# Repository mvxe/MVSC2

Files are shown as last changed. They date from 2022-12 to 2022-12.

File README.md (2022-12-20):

# MVSC2 - MV Stepper Controller V2 

Stepper controller using a STM32F411CEU6 and 6x TMC2208-LA-T.  
Intended as a 3D printer controller, or a standalone 6 stepper driver.  
Also has 6 connectors for endstops or servos.  
Includes design with magnetic proximity sensors as endstops using CH912LSR.  

Design files ready for production at JLCPCB (except connectors, TODO).  

NOTE:  
- In the design I use a lower current setting for the stepper driver, which is meant for weaker steppers. Change sense resistor for normal stepper.  
- It is mean to be attached to a 2040 V slot profile, for cooling.  
- Since fabricating this, JLCPCB now supports connectors so this should be updated (hand soldering a USBC is not fun).  
- The power connector requires hand modification: the leads should be shortened such, and the support pins as well as not to portrude from the other side. Apply superglue for extra strength.  
- A compatible Marlin configuration to be added at a later date.

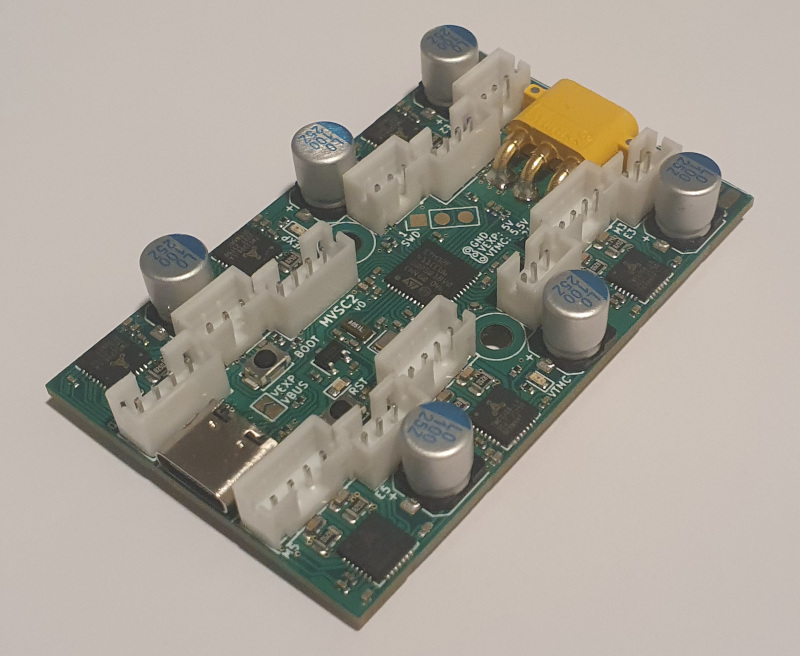
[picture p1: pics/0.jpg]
  
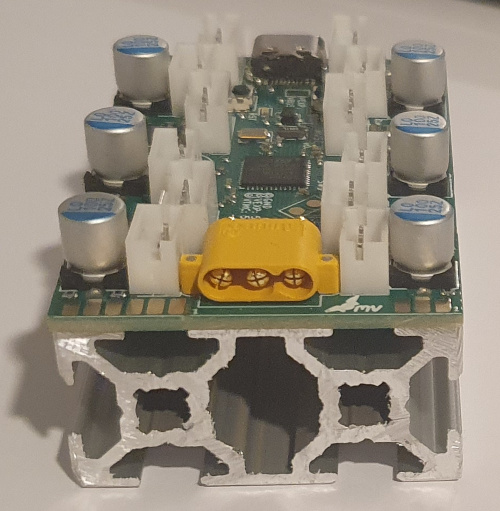
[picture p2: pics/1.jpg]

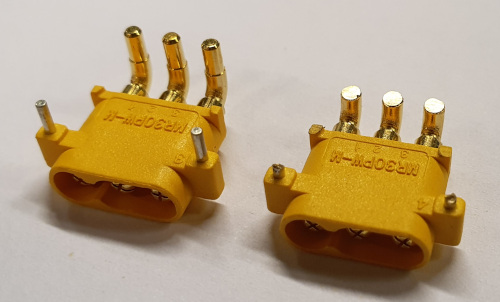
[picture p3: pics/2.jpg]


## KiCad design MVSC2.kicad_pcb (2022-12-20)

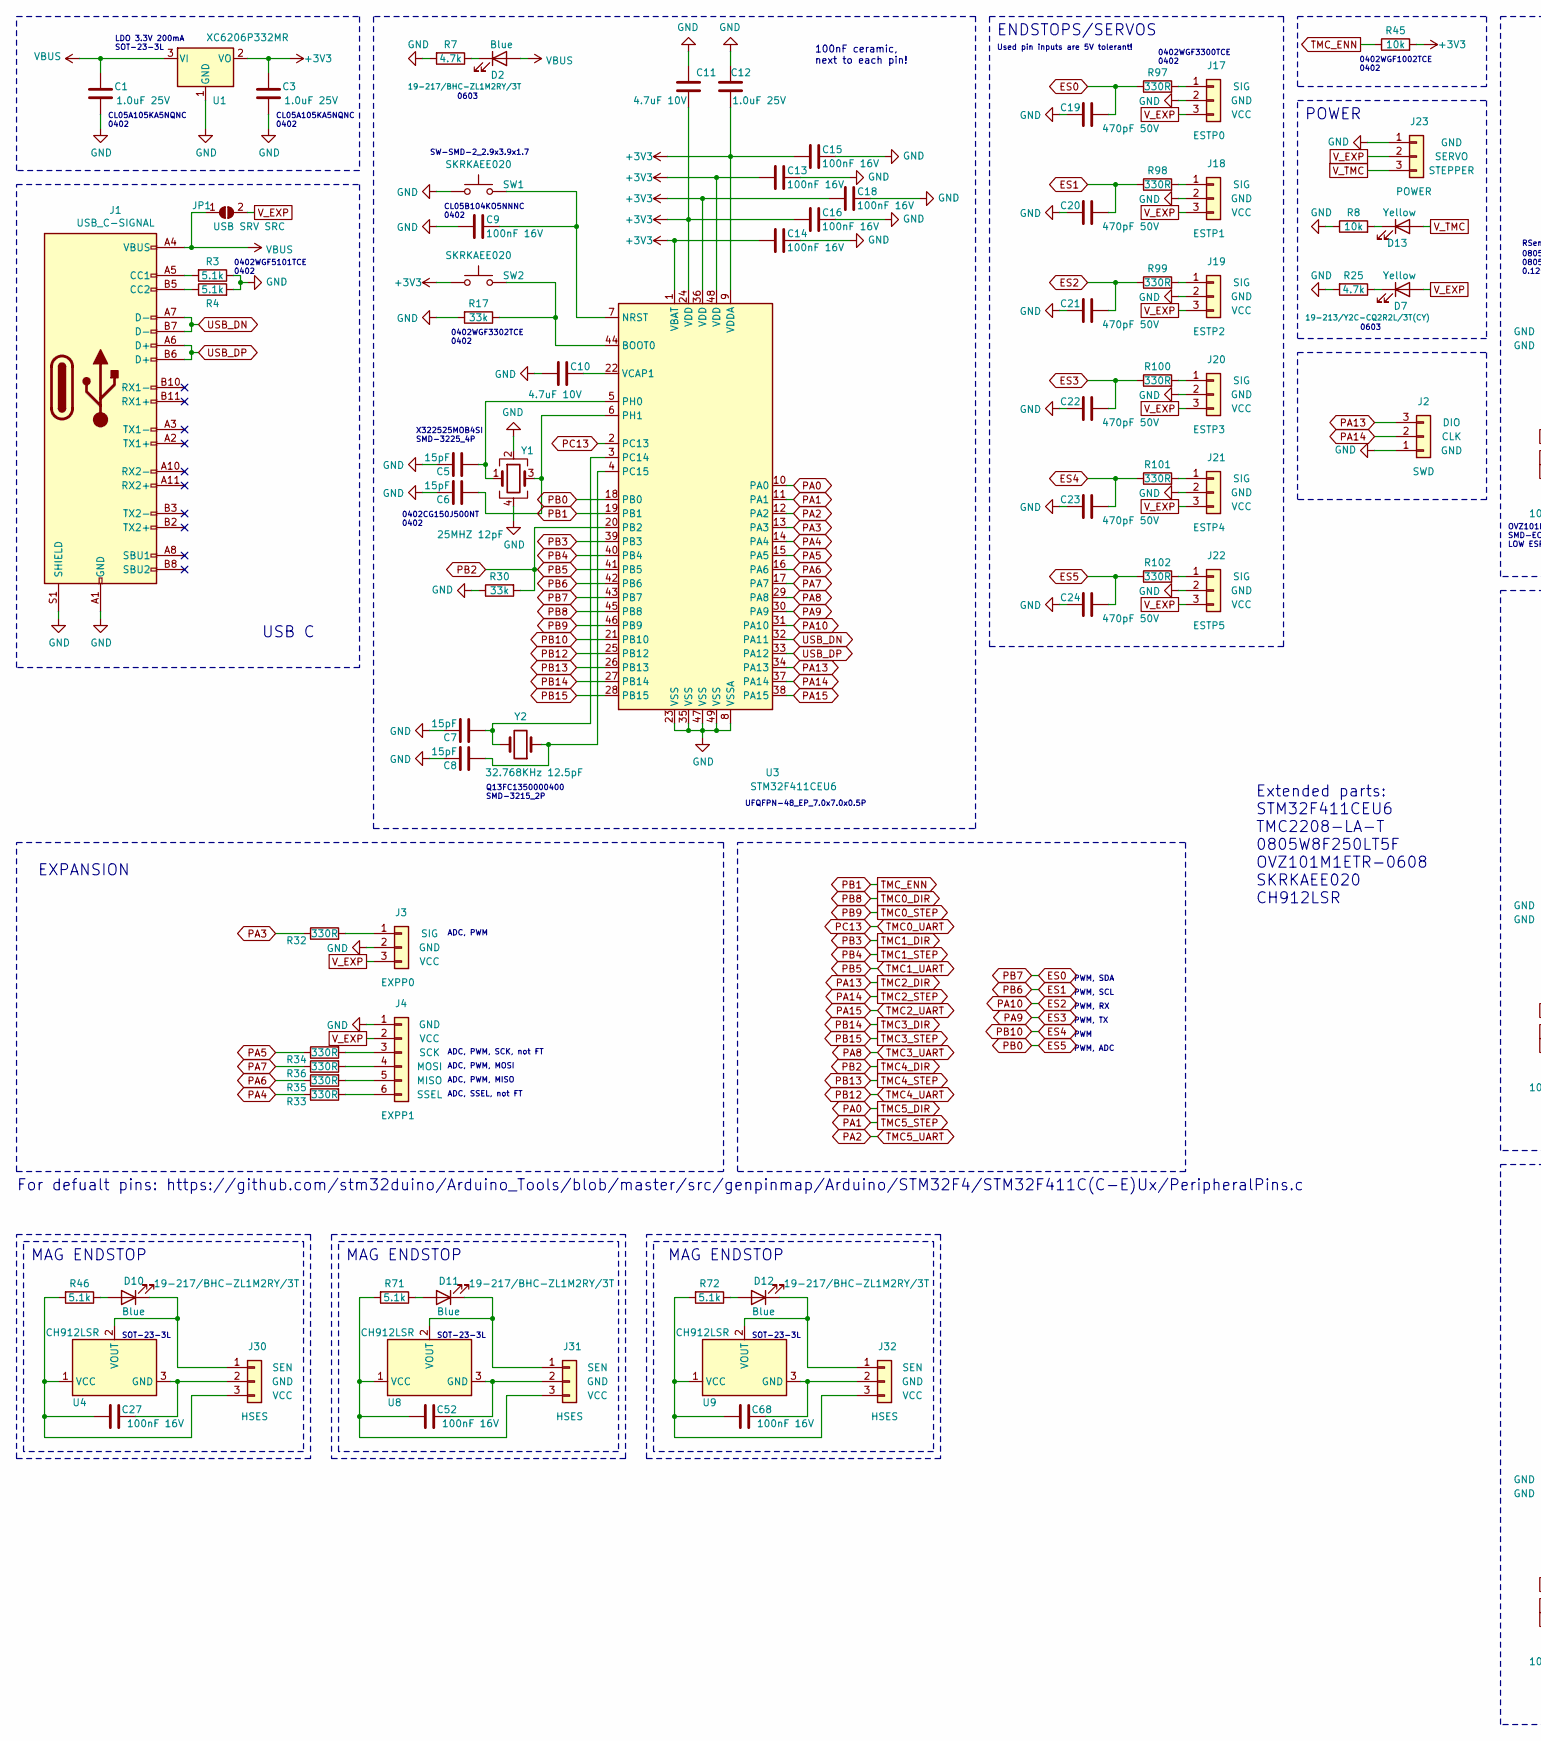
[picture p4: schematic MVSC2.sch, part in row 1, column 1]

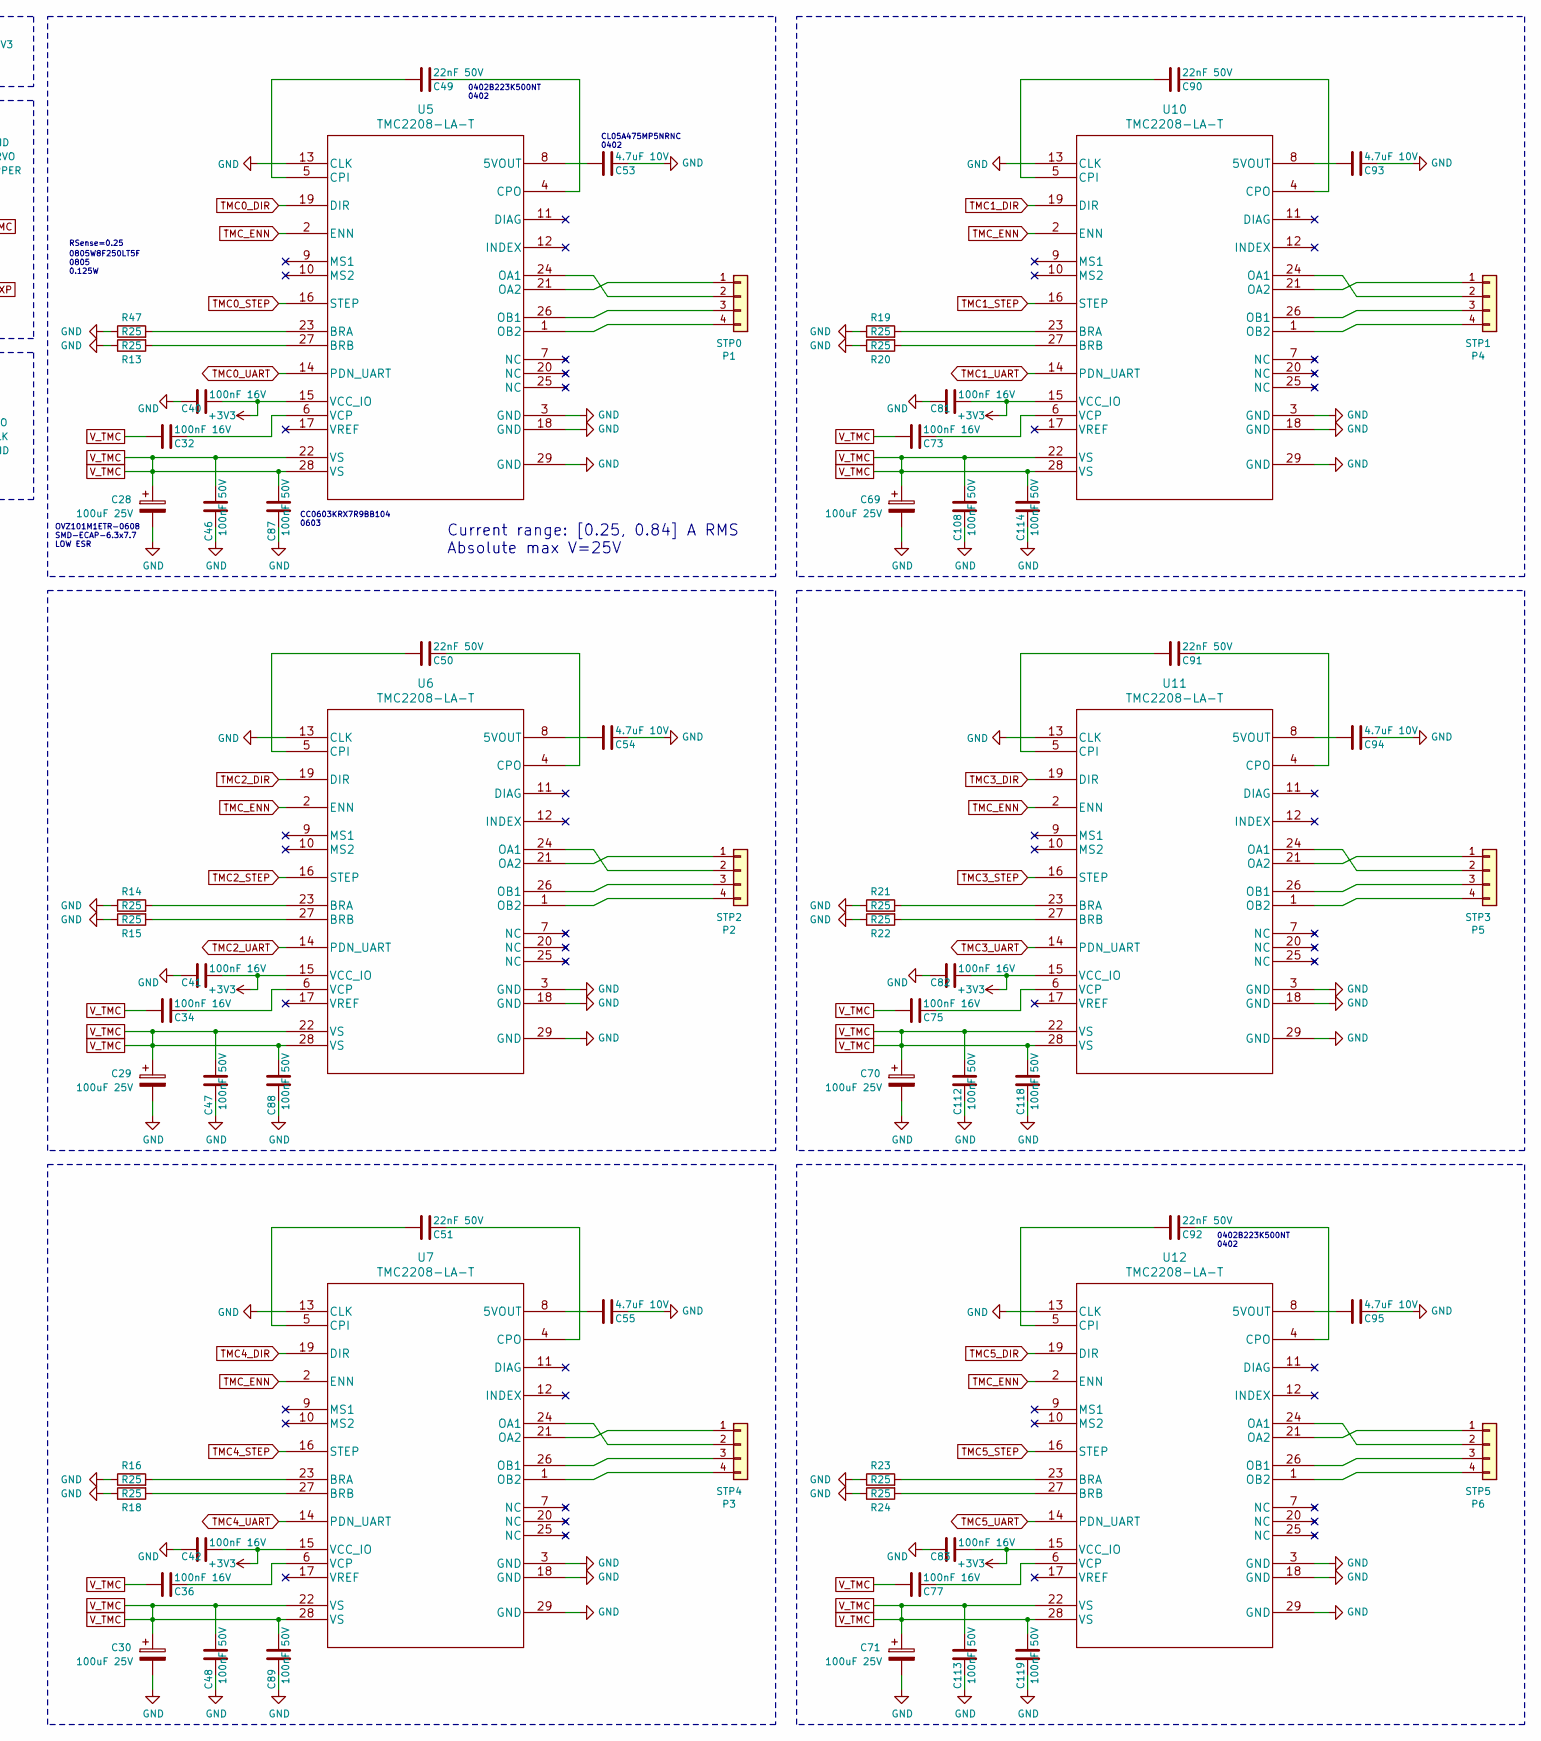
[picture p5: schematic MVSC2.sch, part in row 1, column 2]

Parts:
C1, C3, C12: 1.0uF 25V; C_0402_1005Metric; LCSC C52923
C5, C6, C7, C8: 15pF; C_0402_1005Metric; LCSC C1548
C9, C13, C14, C15, C16, C18, C27, C32, C34, C36, C40, C41, C42, C52, C68, C73, C75, C77, C81, C82, C83: 100nF 16V; C_0402_1005Metric; LCSC C1525
C10, C11, C53, C54, C55, C93, C94, C95: 4.7uF 10V; C_0402_1005Metric; LCSC C23733
C19, C20, C21, C22, C23, C24: 470pF 50V; C_0402_1005Metric; LCSC C1537
C28, C29, C30, C69, C70, C71: 100uF 25V; CP_Elec_6.3x7.7; LCSC C250084
C46, C47, C48, C87, C88, C89, C108, C112, C113, C114, C118, C119: 100nF 50V; C_0603_1608Metric; LCSC C14663
C49, C50, C51, C90, C91, C92: 22nF 50V; C_0402_1005Metric; LCSC C1532
D2, D10, D11, D12: Blue; LED_0603_1608Metric; LCSC C72041
D7, D13: Yellow; LED_0603_1608Metric; LCSC C72038
J1: USB_C-SIGNAL; USB_C_Receptacle_HRO_TYPE-C-31-M-12; LCSC C165948
J2: SWD; PinHeader_1x03_P2.54mm_Vertical
J3: EXPP0; JST_PH_B3B-PH-K_1x03_P2.00mm_Vertical
J4: EXPP1; JST_PH_B6B-PH-K_1x06_P2.00mm_Vertical
J17: ESTP0; JST_PH_B3B-PH-K_1x03_P2.00mm_Vertical
J18: ESTP1; JST_PH_B3B-PH-K_1x03_P2.00mm_Vertical
J19: ESTP2; JST_PH_B3B-PH-K_1x03_P2.00mm_Vertical
J20: ESTP3; JST_PH_B3B-PH-K_1x03_P2.00mm_Vertical
J21: ESTP4; JST_PH_B3B-PH-K_1x03_P2.00mm_Vertical
J22: ESTP5; JST_PH_B3B-PH-K_1x03_P2.00mm_Vertical
J23: POWER; AMASS_MR30PW-M_1x03_P3.50mm_Horizontal
J30, J31, J32: HSES; JST_PH_B3B-PH-K_1x03_P2.00mm_Vertical
JP1: USB SRV SRC; SolderJumper-2_P1.3mm_Open_TrianglePad1.0x1.5mm
P1: STP0; JST_PH_B4B-PH-K_1x04_P2.00mm_Vertical
P2: STP2; JST_PH_B4B-PH-K_1x04_P2.00mm_Vertical
P3: STP4; JST_PH_B4B-PH-K_1x04_P2.00mm_Vertical
P4: STP1; JST_PH_B4B-PH-K_1x04_P2.00mm_Vertical
P5: STP3; JST_PH_B4B-PH-K_1x04_P2.00mm_Vertical
P6: STP5; JST_PH_B4B-PH-K_1x04_P2.00mm_Vertical
R3, R4, R46, R71, R72: 5.1k; R_0402_1005Metric; LCSC C25905
R7, R25: 4.7k; R_0402_1005Metric; LCSC C25900
R8, R45: 10k; R_0402_1005Metric; LCSC C25744
R13, R14, R15, R16, R18, R19, R20, R21, R22, R23, R24, R47: R25; R_0805_2012Metric; LCSC C46216
R17, R30: 33k; R_0402_1005Metric; LCSC C25779
R32, R33, R34, R35, R36, R97, R98, R99, R100, R101, R102: 330R; R_0402_1005Metric; LCSC C25104
SW1, SW2: SKRKAEE020; SW_Push_SPST_NO_Alps_SKRK; LCSC C115357
U1: XC6206P332MR; SOT-23W; LCSC C5446
U3: STM32F411CEU6; QFN-48-1EP_7x7mm_P0.5mm_EP5.6x5.6mm; LCSC C60420
U4, U8, U9: CH912LSR; SOT-23W; LCSC C455294
U5, U6, U7, U10, U11, U12: TMC2208-LA-T; QFN-28-1EP_5x5mm_P0.5mm_EP3.35x3.35mm_ThermalVias; LCSC C115944
Y1: 25MHZ 12pF; Crystal_SMD_3225-4Pin_3.2x2.5mm; LCSC C9006
Y2: 32.768KHz 12.5pF; Crystal_SMD_3215-2Pin_3.2x1.5mm; LCSC C32346

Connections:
+3V3: C3.2, C11.2, C12.1, C13.2, C14.2, C15.2, C16.2, C18.2, C40.1, C41.1, C42.1, C81.1, C82.1, C83.1, R45.2, SW2.1, U1.2 (VO), U3.1 (VBAT), U3.9 (VDDA), U3.24 (VDD), U3.36 (VDD), U3.48 (VDD), U5.15 (VCC_IO), U6.15 (VCC_IO), U7.15 (VCC_IO), U10.15 (VCC_IO), U11.15 (VCC_IO), U12.15 (VCC_IO)
ES0: C19.1, R97.1, U3.43 (PB7)
ES1: C20.1, R98.1, U3.42 (PB6)
ES2: C21.1, R99.1, U3.31 (PA10)
ES3: C22.1, R100.1, U3.30 (PA9)
ES4: C23.1, R101.1, U3.21 (PB10)
ES5: C24.1, R102.1, U3.18 (PB0)
GND: C1.1, C3.1, C5.1, C6.1, C7.1, C8.1, C9.2, C10.2, C11.1, C12.2, C13.1, C14.1, C15.1, C16.1, C18.1, C19.2, C20.2, C21.2, C22.2, C23.2, C24.2, C28.2, C29.2, C30.2, C40.2, C41.2, C42.2, C46.1, C47.1, C48.1, C53.1, C54.1, C55.1, C69.2, C70.2, C71.2, C81.2, C82.2, C83.2, C87.1, C88.1, C89.1, C93.1, C94.1, C95.1, C108.1, C112.1, C113.1, C114.1, C118.1, C119.1, J1.A1 (GND), J1.A12 (GND), J1.B1 (GND), J1.B12 (GND), J1.S1 (SHIELD), J2.1, J3.2, J4.1, J17.2, J18.2, J19.2, J20.2, J21.2, J22.2, J23.1, R3.1, R4.2, R7.2, R8.1, R13.1, R14.1, R15.1, R16.1, R17.2, R18.1, R19.1, R20.1, R21.1, R22.1, R23.1, R24.1, R25.2, R30.1, R47.1, SW1.1, U1.1 (GND), U3.8 (VSSA), U3.23 (VSS), U3.35 (VSS), U3.47 (VSS), U3.49 (VSS), U5.3 (GND), U5.13 (CLK), U5.18 (GND), U5.29 (GND), U6.3 (GND), U6.13 (CLK), U6.18 (GND), U6.29 (GND), U7.3 (GND), U7.13 (CLK), U7.18 (GND), U7.29 (GND), U10.3 (GND), U10.13 (CLK), U10.18 (GND), U10.29 (GND), U11.3 (GND), U11.13 (CLK), U11.18 (GND), U11.29 (GND), U12.3 (GND), U12.13 (CLK), U12.18 (GND), U12.29 (GND), Y1.2, Y1.4
unnamed: C5.2, U3.5 (PH0), Y1.1
unnamed: C6.2, U3.6 (PH1), Y1.3
unnamed: C7.2, U3.3 (PC14), Y2.2
unnamed: C8.2, U3.4 (PC15), Y2.1
unnamed: C9.1, SW1.2, U3.7 (NRST)
unnamed: C10.1, U3.22 (VCAP1)
unnamed: C27.1, J30.3, R46.2, U4.1 (VCC)
unnamed: C27.2, J30.2, U4.3 (GND)
unnamed: C32.1, U5.6 (VCP)
unnamed: C34.1, U6.6 (VCP)
unnamed: C36.1, U7.6 (VCP)
unnamed: C49.1, U5.4 (CPO)
unnamed: C49.2, U5.5 (CPI)
unnamed: C50.1, U6.4 (CPO)
unnamed: C50.2, U6.5 (CPI)
unnamed: C51.1, U7.4 (CPO)
unnamed: C51.2, U7.5 (CPI)
unnamed: C52.1, J31.3, R71.2, U8.1 (VCC)
unnamed: C52.2, J31.2, U8.3 (GND)
unnamed: C53.2, U5.8 (5VOUT)
unnamed: C54.2, U6.8 (5VOUT)
unnamed: C55.2, U7.8 (5VOUT)
unnamed: C68.1, J32.3, R72.2, U9.1 (VCC)
unnamed: C68.2, J32.2, U9.3 (GND)
unnamed: C73.1, U10.6 (VCP)
unnamed: C75.1, U11.6 (VCP)
unnamed: C77.1, U12.6 (VCP)
unnamed: C90.1, U10.4 (CPO)
unnamed: C90.2, U10.5 (CPI)
unnamed: C91.1, U11.4 (CPO)
unnamed: C91.2, U11.5 (CPI)
unnamed: C92.1, U12.4 (CPO)
unnamed: C92.2, U12.5 (CPI)
unnamed: C93.2, U10.8 (5VOUT)
unnamed: C94.2, U11.8 (5VOUT)
unnamed: C95.2, U12.8 (5VOUT)
unnamed: D2.1 (K), R7.1
unnamed: D7.1 (K), R25.1
unnamed: D10.1 (K), J30.1, U4.2 (VOUT)
unnamed: D10.2 (A), R46.1
unnamed: D11.1 (K), J31.1, U8.2 (VOUT)
unnamed: D11.2 (A), R71.1
unnamed: D12.1 (K), J32.1, U9.2 (VOUT)
unnamed: D12.2 (A), R72.1
unnamed: D13.1 (K), R8.2
unnamed: J1.A5 (CC1), R3.2
unnamed: J1.B5 (CC2), R4.1
unnamed: J3.1, R32.2
unnamed: J4.3, R34.2
unnamed: J4.4, R36.2
unnamed: J4.5, R35.2
unnamed: J4.6, R33.2
unnamed: J17.1, R97.2
unnamed: J18.1, R98.2
unnamed: J19.1, R99.2
unnamed: J20.1, R100.2
unnamed: J21.1, R101.2
unnamed: J22.1, R102.2
unnamed: P1.1, U5.21 (OA2)
unnamed: P1.2, U5.24 (OA1)
unnamed: P1.3, U5.26 (OB1)
unnamed: P1.4, U5.1 (OB2)
unnamed: P2.1, U6.21 (OA2)
unnamed: P2.2, U6.24 (OA1)
unnamed: P2.3, U6.26 (OB1)
unnamed: P2.4, U6.1 (OB2)
unnamed: P3.1, U7.21 (OA2)
unnamed: P3.2, U7.24 (OA1)
unnamed: P3.3, U7.26 (OB1)
unnamed: P3.4, U7.1 (OB2)
unnamed: P4.1, U10.21 (OA2)
unnamed: P4.2, U10.24 (OA1)
unnamed: P4.3, U10.26 (OB1)
unnamed: P4.4, U10.1 (OB2)
unnamed: P5.1, U11.21 (OA2)
unnamed: P5.2, U11.24 (OA1)
unnamed: P5.3, U11.26 (OB1)
unnamed: P5.4, U11.1 (OB2)
unnamed: P6.1, U12.21 (OA2)
unnamed: P6.2, U12.24 (OA1)
unnamed: P6.3, U12.26 (OB1)
unnamed: P6.4, U12.1 (OB2)
unnamed: R13.2, U5.27 (BRB)
unnamed: R14.2, U6.23 (BRA)
unnamed: R15.2, U6.27 (BRB)
unnamed: R16.2, U7.23 (BRA)
unnamed: R17.1, SW2.2, U3.44 (BOOT0)
unnamed: R18.2, U7.27 (BRB)
unnamed: R19.2, U10.23 (BRA)
unnamed: R20.2, U10.27 (BRB)
unnamed: R21.2, U11.23 (BRA)
unnamed: R22.2, U11.27 (BRB)
unnamed: R23.2, U12.23 (BRA)
unnamed: R24.2, U12.27 (BRB)
unnamed: R47.2, U5.23 (BRA)
PA0: U3.10 (PA0), U12.19 (DIR)
PA1: U3.11 (PA1), U12.16 (STEP)
PA2: U3.12 (PA2), U12.14 (PDN_UART)
PA3: R32.1, U3.13 (PA3)
PA4: R33.1, U3.14 (PA4)
PA5: R34.1, U3.15 (PA5)
PA6: R35.1, U3.16 (PA6)
PA7: R36.1, U3.17 (PA7)
PA8: U3.29 (PA8), U11.14 (PDN_UART)
PA13: J2.3, U3.34 (PA13), U6.19 (DIR)
PA14: J2.2, U3.37 (PA14), U6.16 (STEP)
PA15: U3.38 (PA15), U6.14 (PDN_UART)
PB1: R45.1, U3.19 (PB1), U5.2 (ENN), U6.2 (ENN), U7.2 (ENN), U10.2 (ENN), U11.2 (ENN), U12.2 (ENN)
PB2: R30.2, U3.20 (PB2), U7.19 (DIR)
PB3: U3.39 (PB3), U10.19 (DIR)
PB4: U3.40 (PB4), U10.16 (STEP)
PB5: U3.41 (PB5), U10.14 (PDN_UART)
PB8: U3.45 (PB8), U5.19 (DIR)
PB9: U3.46 (PB9), U5.16 (STEP)
PB12: U3.25 (PB12), U7.14 (PDN_UART)
PB13: U3.26 (PB13), U7.16 (STEP)
PB14: U3.27 (PB14), U11.19 (DIR)
PB15: U3.28 (PB15), U11.16 (STEP)
PC13: U3.2 (PC13), U5.14 (PDN_UART)
USB_DN: J1.A7 (D-), J1.B7 (D-), U3.32 (PA11)
USB_DP: J1.A6 (D+), J1.B6 (D+), U3.33 (PA12)
VBUS: C1.2, D2.2 (A), J1.A4 (VBUS), J1.A9 (VBUS), J1.B4 (VBUS), J1.B9 (VBUS), JP1.1 (A), U1.3 (VI)
V_EXP: D7.2 (A), J3.3, J4.2, J17.3, J18.3, J19.3, J20.3, J21.3, J22.3, J23.2, JP1.2 (B)
V_TMC: C28.1, C29.1, C30.1, C32.2, C34.2, C36.2, C46.2, C47.2, C48.2, C69.1, C70.1, C71.1, C73.2, C75.2, C77.2, C87.2, C88.2, C89.2, C108.2, C112.2, C113.2, C114.2, C118.2, C119.2, D13.2 (A), J23.3, U5.22 (VS), U5.28 (VS), U6.22 (VS), U6.28 (VS), U7.22 (VS), U7.28 (VS), U10.22 (VS), U10.28 (VS), U11.22 (VS), U11.28 (VS), U12.22 (VS), U12.28 (VS)

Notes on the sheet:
100nF ceramic, next to each pin!
CL05A105KA5NQNC 0402
LDO 3.3V 200mA SOT-23-3L
X322525MOB4SI SMD-3225_4P
Q13FC1350000400 SMD-3215_2P
Extended parts: STM32F411CEU6 TMC2208-LA-T 0805W8F250LT5F OVZ101M1ETR-0608 SKRKAEE020 CH912LSR
UFQFPN-48_EP_7.0x7.0x0.5P
CL05B104KO5NNNC 0402
0402CG150J500NT 0402
0402WGF3302TCE 0402
0402WGF5101TCE 0402
0402WGF1002TCE 0402
Current range: [0.25, 0.84] A RMS Absolute max V=25V
OVZ101M1ETR-0608 SMD-ECAP-6.3x7.7 LOW ESR
CL05A475MP5NRNC 0402
0402B223K500NT 0402
CC0603KRX7R9BB104 0603
SW-SMD-2_2.9x3.9x1.7
0805W8F250LT5F 0805 0.125W
RSense=0.25
POWER
EXPANSION
USB C
0402WGF3300TCE 0402
0603
For defualt pins: https://github.com/stm32duino/Arduino_Tools/blob/master/src/genpinmap/Arduino/STM32F4/STM32F411C(C-E)Ux/PeripheralPins.c
MAG ENDSTOP
SOT-23-3L
ENDSTOPS/SERVOS
PWM, SDA
PWM, SCL
ADC, PWM, MOSI
ADC, PWM, MISO
ADC, PWM, SCK, not FT
PWM, RX
PWM, TX
PWM
Used pin inputs are 5V tolerant!
PWM, ADC
ADC, PWM

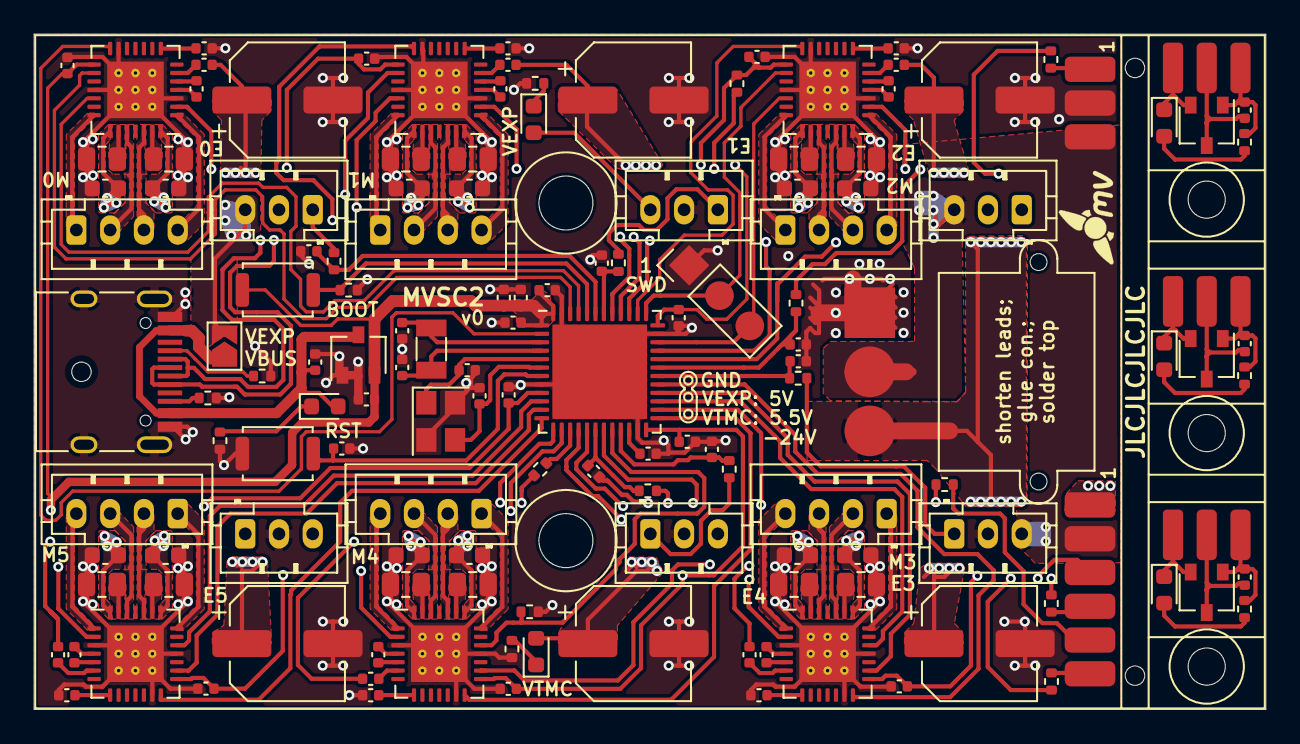
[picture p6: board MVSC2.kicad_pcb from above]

Board: 4 copper layers, 73.0 x 40.0 mm, 145 parts (0 on the bottom side), 132 nets.

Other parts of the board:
e: MountingHole_2.2mm_M2
tooling: MountingHole_2.2mm_M2
tooling#2: MountingHole_2.2mm_M2

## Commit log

2022-12-20 panelized but too expensive for jlcpcb
    [MVSC2.kicad_pcb, MVSC2.sch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]
2022-12-20 going to rearrange everything
    [MVSC2.kicad_pcb]
2022-12-20 working layout - needs tripple checking
    [MVSC2.kicad_pcb, MVSC2.sch]
2022-12-20 fixed all drc errors and checked zones; still TODO: check everything
    [MVSC2.kicad_pcb]
2022-12-20 working version with mosfets
    [MVSC2.kicad_pcb, MVSC2.sch]
2022-12-20 final, ordered
    [MVSC2.kicad_pcb, MVSC2.sch]
